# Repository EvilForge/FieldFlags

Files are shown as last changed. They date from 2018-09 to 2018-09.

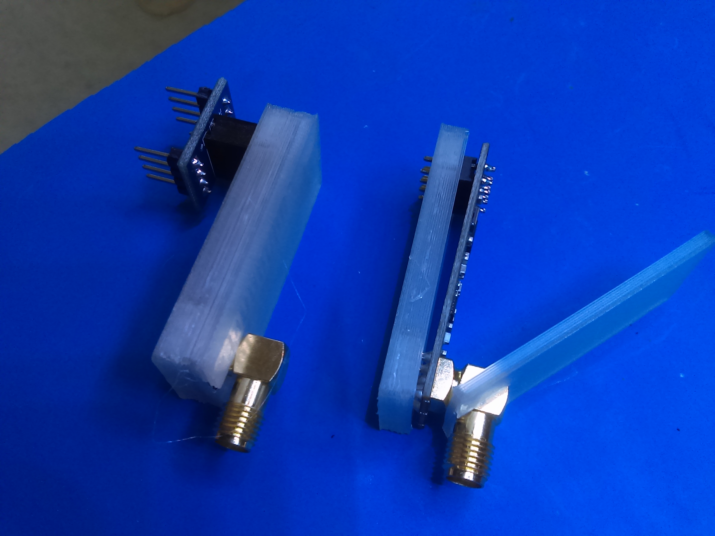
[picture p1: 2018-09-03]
IMAG0442.jpg

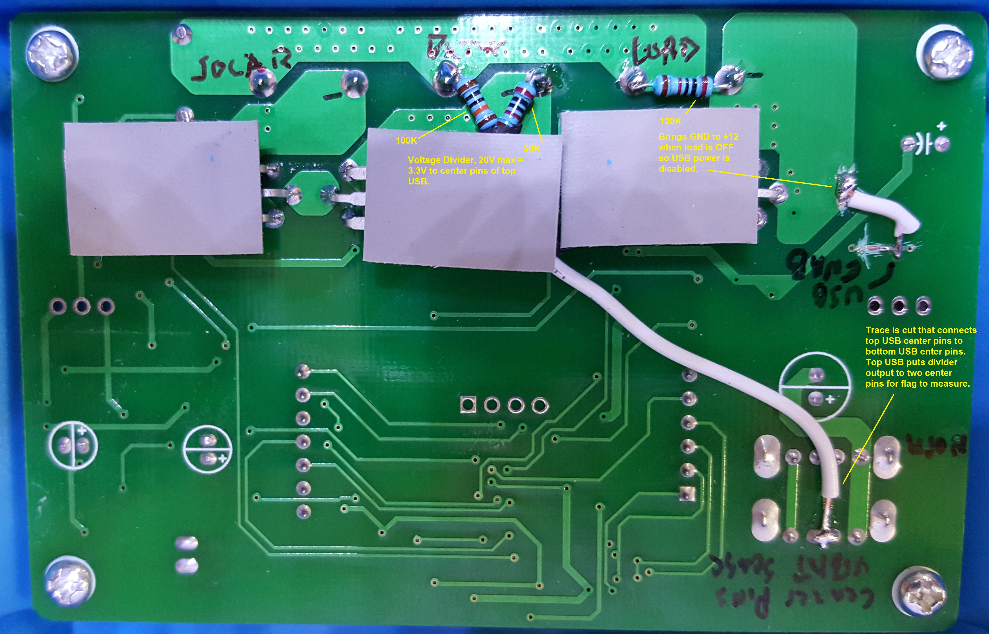
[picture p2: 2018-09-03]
SolarCharge-Bent.jpg

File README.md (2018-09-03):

# FieldFlags
An airsoft field remote flag (wireless mesh) system with internet feedback and control for players and operators.

This was a project I have abandoned, but got fairly well into things before I ran out of time and energy to tweak it. Unfortunately, there are multiple constraints such as very slow internet connectivity and multiple wireless interference issues as well as the code starting to get very complex. 

Ideally, this is a esp8266 main controller, with pro mini nodes and repeaters that all use the NRF24L01 radios to form a healing mesh network on the 2.4 GHz band (not wifi, but the same frequency).  The main controller is centrally located on the field and uses a wireless hotspot to report data and take commands from a web server running php, and mysql for a db. 

A web page that the field operators access allows statistics for the game play, field light control, and another web page can offer the players read only status updates.

Different game modes are baked into the controller but the most useful one - aside from general get read, game on, game end feedback to the players, was capture the flag mode, as the system would track the amount of time the player teams owned each flag.

This system was used in a few large events and did work in the basic mode but started to fail constantly, due to unknown reasons. I suspect wireless band interference (perhaps due to lots of drones in use?), but as the nodes are all pro mini theres not a lot of ways i could easily (or cost effectively) really do debug logging.

We also tried to add in a node that could play prerecorded mp3 sounds or songs based on a trigger from the admin, however, the current demands of the drok mp3 player made that flag consume a lot of battery.. and there was a limit to how much we could spend on solar charging and battery systems.

So I've released the code and work i did up to this point to the community, in hopes that it might help someone else out. Note than in a large part the framework for nodes and reporting and traffic management was handled by the mysensors 2.1 framework. I generally modded and enhanced the code for my uses and did not use a typical setup with a windows or ras-pi or other "controller" as you would in a home automation scenario.. in this system the wifi gateway also did a lot of the code and game flow work, in conjunction with getting and sending data to the mysqldb via php.

Note that i really dont think this is a bad setup - you may have a much simpler scenario where you just need to remotely alert people across a large area about status.. this setup might work realy well for that - but then the basic mysensors network might also do that without having to add in the mods that i used, either.

Enjoy! I wont be supporting this but if i notice a question i'll try to answer as much as i can remember..

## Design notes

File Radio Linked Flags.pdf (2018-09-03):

NOTICE – This manual is part of a system designed for use by the D14 airsoft fields for entertainment and game control purposes. No item described in this document is dangerous or life-threatening in the course of normal Airsoft Game Rules. All trademarked names and logos and titles are owned by their respective copyright owners and all use is claimed as “fair use” for parody purposes.

# OPERATING MANUAL: RADIO LINKED FLAGS

SYSTEM OVERVIEW

The radio linked flag system is based on concepts and a large amount of work completed by the MySensors.org group. While the main intent of the MySensors system is home automation, the system appears suitable for use to control game play and various devices on the D14 Airsoft field. Extensive customization is included in the resulting system. While the system is NOT intended to be resold, submission of the customized code used in the project will generally NOT be released back to the open source community at this time.

The MySensors.org system implemented at D14 relies on cheap microcontrollers (Arduino NANOs) connected to a low cost RF radio (nRF24L01) which act as “nodes”in a multi-tier star organization. End nodes transmit to repeater nodes, which in turn talk to either the gateway node or other repeater nodes. The gateway connects to a controller, which controls the commands issued to the node. End nodes can move around physically (repeating nodes should not move however) and will reattach to the network. Addressing and routing of the nodes is controlled by the nodes, repeaters and gateway nodes.

Authorization and digital signing of messages is implemented to prevent rogue interference or MITM attacks (either by players or who knows what!). Each node has a hard coded ID number, representing a flag or building or device.

The following manual is intended for qualified personnel only. Operation and deployment of the radio linked flags requires familiarity with the operating modes and options for maximum effectiveness. Your effort in reviewing and practicing with the system, as well as anticipating how adept the players are at following the instructions, will be rewarded with smooth gameplay and maximum player involvement.

What follows is the installation, operation and maintenance guide for this system.

LOCATION OF INSTALLATIONS

The radio-linked flag installation is spread across the D14 playing field. Due to the size of the field (45+ acres) having admin staff keep up to date on flag status (who owns it) or control players (start/stop games) is a significant burden. Flags may have up to 500 meters between them, but are mainly clustered around the town center. Ideally placed, the “comms” building is intended to look like a communications outpost, and in in fact, the ideal location for the gateway and possibly the controller node as well.

CONTENTS

NORMAL OPERATION PROCEDURES

FLAG NODE MODES OF OPERATION

The flag node contains one button, an RGB light and a beeper as the primary means of interacting with players. Generally, players press a button on the flag to advance thru the colors of the flag, or to indicate they are ready to begin gameplay.

The flag has several different “modes” and the light and buzzer vary with each mode:

Flag Mode | Light | Sound
Sleeping | Off | None
Game ON | Solid Green | 3- 1 sec beeps, 1 2 sec beep (like a light tree race start)
Standby | Solid Yellow | 1 sec beep when mode starts
Two Minute Warning | White/Green alternates twice with 2 sec pause, repeats 3 times. | Beep when white shown, in sync with white light.
Game END | Solid Red | 15 second solid tone.
Blind Man/Distress | Red SOS flash | SOS Beep
GREEN CONTROLLED | Green solid, with 1/4s no color every second. | 1 beep per second.
TAN CONTROLLED | Orange solid, with 1/4s no color every second | 2 beeps together, every second.
BLUE CONTROLLED | Blue Solid, with 1/4s no color every second | 3 beeps together, every second.

More stuff here…

STRONG RF EMISSIONS NEAR THE NODES MAY INTERRUPT COMMUNICATIONS. IT IS RECCOMMENDED THAT HIGH POWER RADIOS DOE ONT TRANSMIT NEAR NODES AND OTHER 2.4-2.5GHZ DEVICES (BLUETOOTH, DRONES, WIFI) ARE NOT OPERATED WITHIN SEVERAL FEET OF THE DEVICE.

WARNING. ALWAYS HAVE A BACKUP GAME PLAY PLAN IN CASE THE SYSTEM IS DOWN. SEVERAL DIFFERENT KINDS OF ISSUES CAN AFFECT THE RADIO LINKS, FROM WEATHER TO INTERFERENCE TO TERRAIN AND VEGETATION GROWTH, TO COLORBLIND PLAYERS. BE PREPARED!

INITIAL CONFIGURATION/RECONFIGURATION

Initial configuration or altering the system settings is performed by accessing the programming menu.

PROGRAMMING MENU DETAILS

PROP INTEGRATION NOTE

Props used on the field can be integrated into the system. The expected minimum amount of integration will allow starting or resetting the prop remotely, finding its status, and in some cases remotely disabling or detonating the device. However, in the initial deployment, props will not be incorporated.

FLAG GAME – FLAG CONTROL

Junk junk junk

GAME FLOW

The initial flow of this game is as follows:

1. System blah blah

SYSTEM MAINTENANCE

OVERVIEW

System maintenance includes items such as pre-operation checks, battery charging and replacement, and node replacement. The system is generally built to handle normal use but any time the device is dropped, kicked or knocked over, an inspection of the device should be performed.

Modifying the code operation – aside from the configuration options in the programming menu – is not covered in this manual. The unit uses C++ Arduino style programming language with an Arduino Nano controller and an nRF24L01+ radio device, and does support direct USB connections for reprogramming. Please contact the D14 owners for questions about the program source code or design documentation.

TROUBLESHOOTING NODE CONNECTIVITY

Note that if a node cannot connect at power-up there may be.

Strong RF emissions near the device have been proven to cause undesired operation, including hanging the controller, erroneous entry, etc. It is recommended that RF transmitters are NOT operated within several feet of the device.

If the device display becomes garbled or appears to hang, power the system down with the access key, then power it back on. The last program will be restarted.

If the buzzer or LEDs run continuously, the MOSFET devices may have failed. MOSFET devices typically (eventually) fail as a short circuit. Turn off the node and replace it with a functioning node if a power cycle does not resolve the issue.

OPENING THE NODE CASE

The case should be opened using the….

ALWAYS DISCONNECT ONE OR BOTH OF THE MAIN BATTERY CONNECTORS WHEN PERFORMING SERVICE.

MOSFETS AND SEVERAL COMPONENTS ARE ‘GROUND-SWITCHED’. WHICH MEANS THEY RECEIVE CONSTANT POWER FROM THE BATTERY + RAIL, AND GROUND IS SWITCHED BY THE MOSFET DEVICES. THIS MEANS THE MOSFET TABS AND HEAT-SINKS WILL NORMALLY BE RESTING AT +12VDC DURING OPERATION.

BATTERY CHARGING

The on-board solar charging circuit may take several hours due to battery capacity. Battery is considered charged when the voltage reaches 11 VDC. Battery voltage less than 9V is not recommended and can damage the NiMh battery.

If a battery is dead and the node is needed for gameplay immediately, swap the NiMh battery with a charged one.

NOTE – THE INTERNAL CHARGER IS INTELLIGENT, AND WILL SWITCH TO FLOAT MODE AUTOMATICALLY. THE DEVICE CAN BE LEFT PLUGGED IN INDEFINITELY WITHOUT CAUSING BATTERY DAMAGE.

BATTERY REPLACEMENT

As this unit uses a 9.6V NiMh Airsoft battery with a deans connector. Please replace the battery with a suitable sized replacement.

Unscrew the bracket holding the battery down and one or more of the side screws to free the battery.

This is a standard battery design, and any battery with similar specifications can be used – whether it was sold for airsoft or R/C use. A higher capacity battery will provide more run time during low sunlight periods, but the current draw of the flag is not high and does not require high capacity batteries.

Dispose of or recycle according to local ordinances.

FUSE REPLACEMENT

Fuses should not typically blow unless an internal short develops in the device or a component. Before replacing a fuse, investigate the component that blew the fuse and verify it is not malfunctioning. If the main 3A fuse blows, open the battery cover to switch it out.

Component | Fuse Size | Purpose
Main Battery 3 | 3A | Main power for all systems.

AUXILLARY INFORMATION/SPECIFICATIONS

FLAG NODE INTERNAL COMPONENT LIST

The following components are used in this device.

Component

Main Battery. 9.6V NiMh battery with deans connector. 3A Main fuse on battery.

Control box. Arduino Nano controller with custom program, power regulation as well as control MOSFET switches and the radio module. Control system fuses and battery charger. Main power switch turns on the control electronics and LED/audio.

“Main Button” – main button used to interact with the device.

Power Switch. Switches power to control box only – however this will generally turn off all components. The charger will operate regardless of system power switch state.

LED display – Red, Blue and Green LED displays.

INTERNAL COMPONENTS:

CONTROL BOX:

MAIN CPU BOARD

MISCELLANEOUS SPECS:

Weight: .3 Kg or 2 lbs.

Width: 0.1M or 4 in.

Height: 0.3M or 10 in.

Power Supply: Internal 9.6V NiMh battery, deans connector.

Power Draw: 3A Max, intermittent. 2mA in sleep mode.

Theoretical Battery Life – 8Ahr/(1A average)=8 hours? Exact time estimates depend heavily on options chosen and amount of game play, as well as amount of available strong sunlight.
Date of Creation: September 31st, 2016.

Paint Codes: RUST-OLEUM Hammered spray paints, Silver 7213

Fuel Rod/Canister modification: The fuel rods or canisters must have a strong magnet to trigger the sensor in the bottom left canister slot (over the left support). A small strong magnet is embedded in the bottom of the canister slot to trigger Fuel Rod sensors as well.

Schematic:

QUICK REFERENCE SHEET

Print copies of the following sheet for in-field reference.

DISCLAIMER AND WARNINGS

This device is designed to enhance game play in an Airsoft scenario game. It is not dangerous or life threatening, assuming normal Airsoft game play rules are followed. Following typical rules, especially eye protection, when the BB Cannon is enabled should protect players from injury. The device is not intended to be moved during game play, especially by less than 2 people. Always instruct players to keep clear of the BB Cannon at all times, regardless of whether the system is powered or armed. When not in use, cover the cannon to prevent debris from entering or protect if accidental discharge occurs.

While it should be readily apparent to anyone this is a prop, based on design, it is still prudent to cover and conceal the device from general public view when not in use on the playing field.

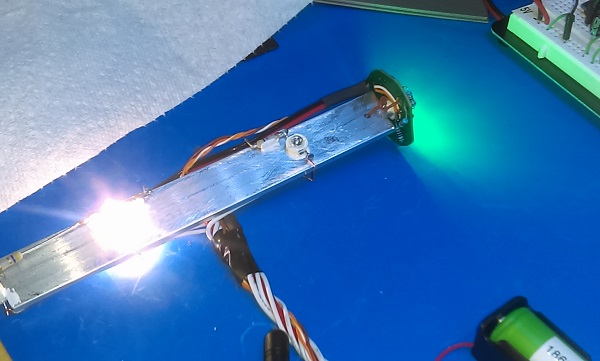
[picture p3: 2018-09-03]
IMAG0454.jpg

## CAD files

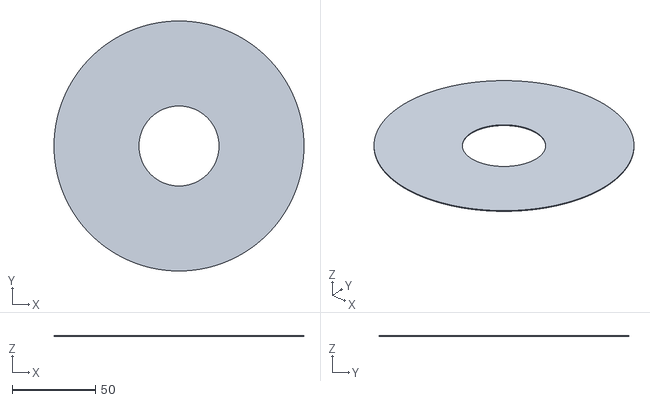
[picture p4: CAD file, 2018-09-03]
Flag LED SunShield.stl
150.0 x 150.0 x 0.5

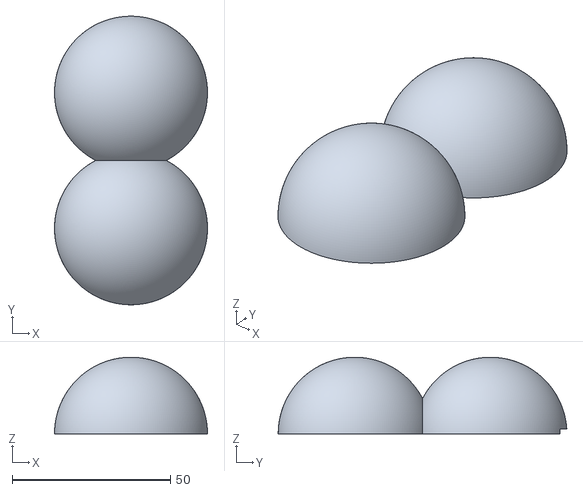
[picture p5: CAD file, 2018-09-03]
Flag LED Bubble.stl
48.4 x 91.3 x 24.2

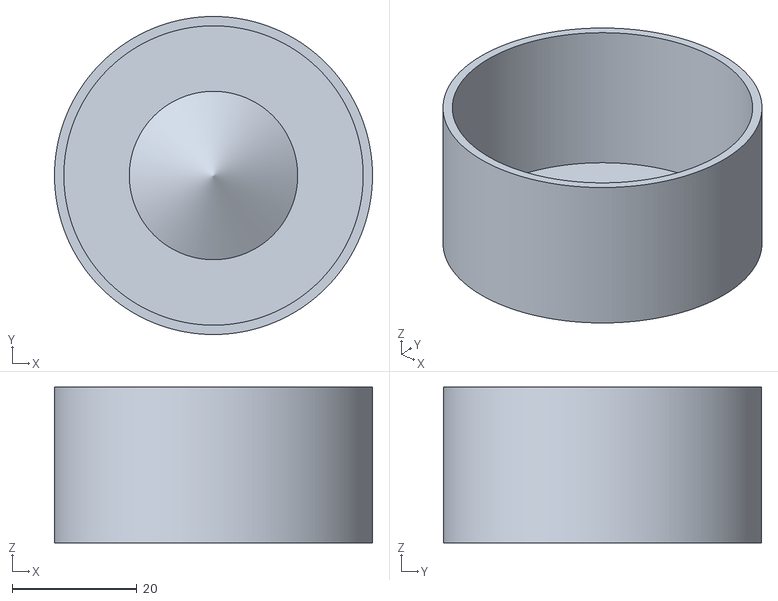
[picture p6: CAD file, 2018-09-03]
Flag LED Top.stl
51.0 x 51.0 x 25.0

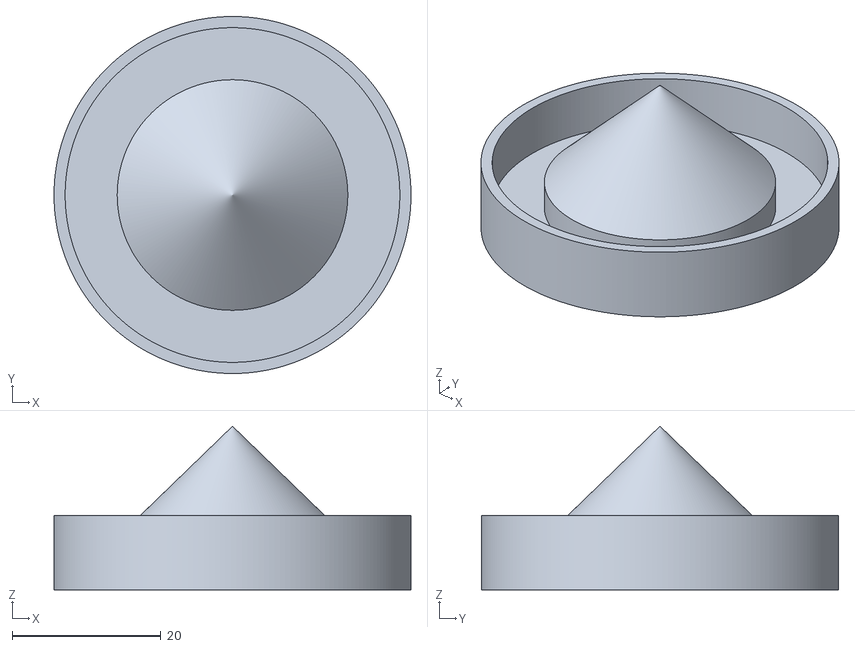
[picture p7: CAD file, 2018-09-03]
Flag LED Tube Top.stl
48.0 x 48.0 x 22.0

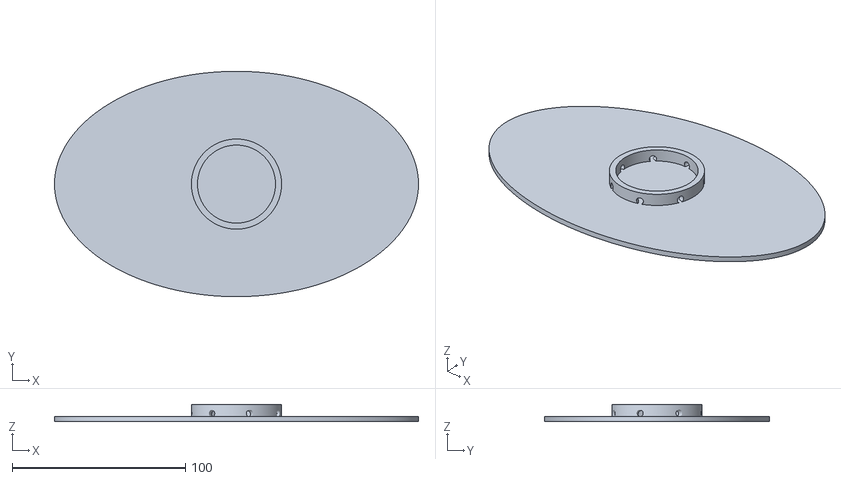
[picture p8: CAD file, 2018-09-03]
Flag LED Wide Top.stl
210.0 x 130.0 x 10.0

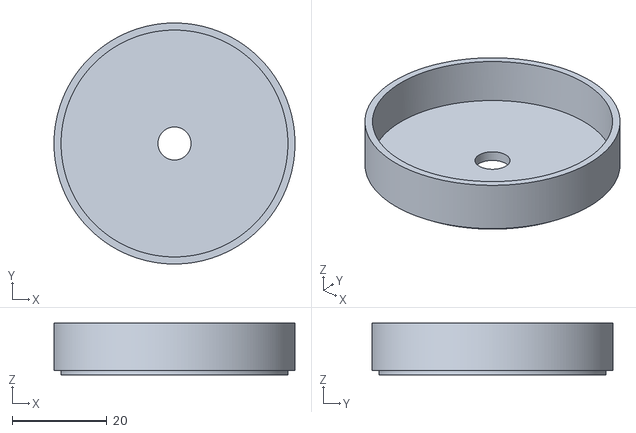
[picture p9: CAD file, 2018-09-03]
Flag LED Spacer.stl
51.0 x 51.0 x 11.0

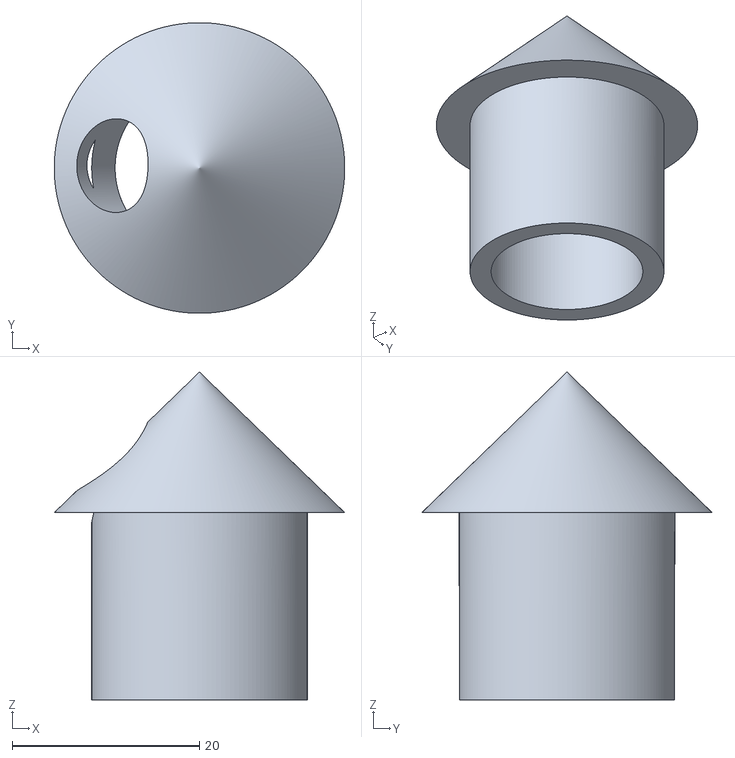
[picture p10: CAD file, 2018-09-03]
Flag LED Tube Base.stl
31.0 x 31.0 x 35.0

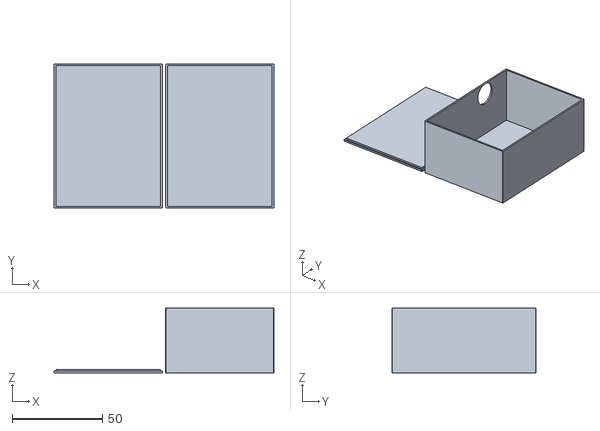
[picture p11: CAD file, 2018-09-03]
Flag GW Box.stl
121.9 x 80.0 x 36.0

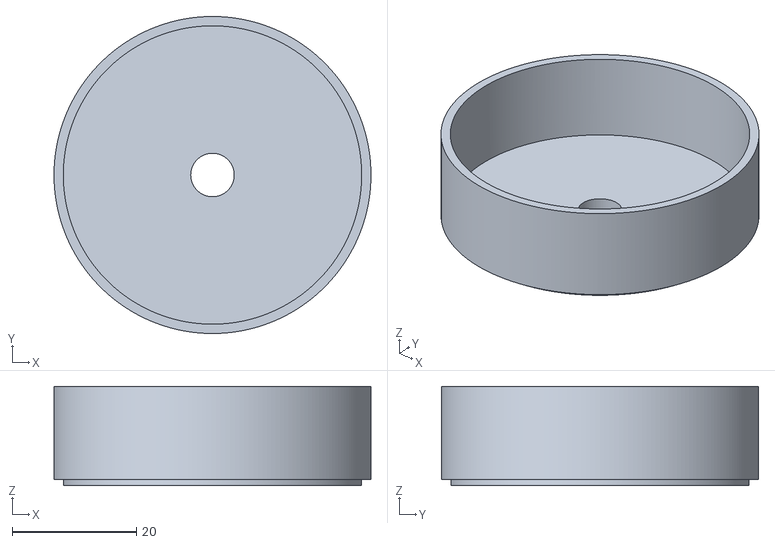
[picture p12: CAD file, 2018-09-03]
Flag LED Mid.stl
51.0 x 51.0 x 16.0

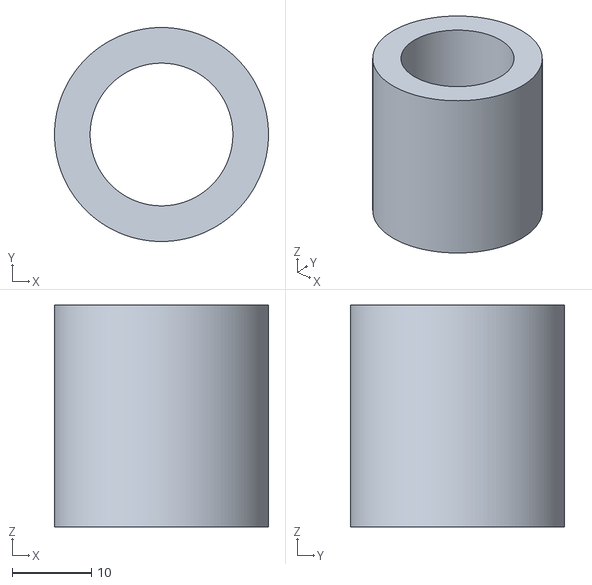
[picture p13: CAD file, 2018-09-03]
Flag Pole Bushing.stl
27.0 x 27.0 x 28.0

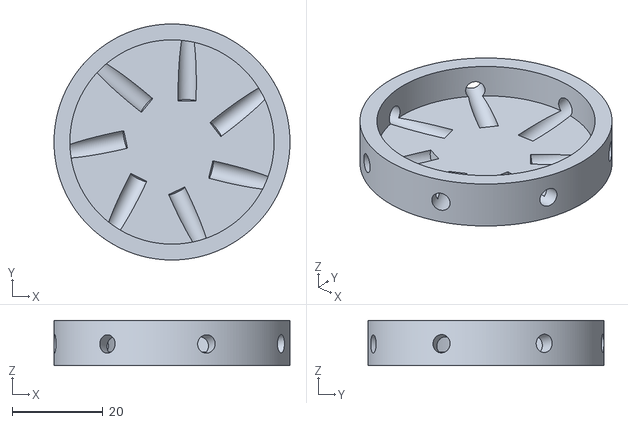
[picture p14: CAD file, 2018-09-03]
Flag LED New Top.stl
52.0 x 52.0 x 10.00

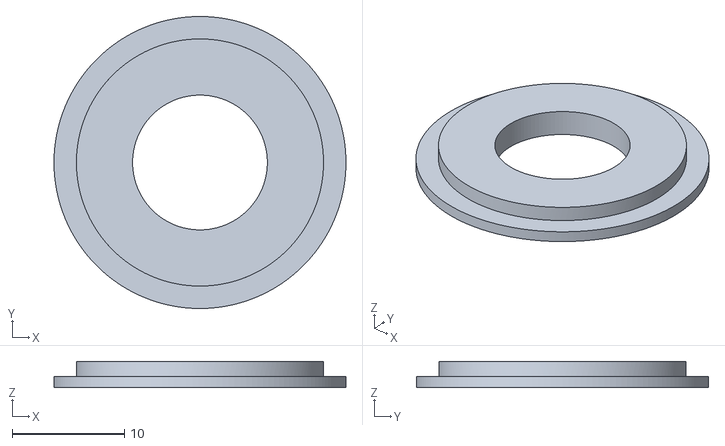
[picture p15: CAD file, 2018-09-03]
Flag Switch Bushing.stl
26.0 x 26.0 x 2.35

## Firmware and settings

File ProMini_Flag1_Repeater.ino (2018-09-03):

// ProMini E-Flag Repeater. Copyright Reid Bush 2017
//#define MY_DEBUG // Keep Debug off, it uses tons of prog memory.
#define MY_REPEATER_FEATURE
#define MY_RADIO_NRF24
#define MY_RF24_PA_LEVEL RF24_PA_MAX
#define MY_RF24_CHANNEL 83
#define MY_NODE_ID 1
#define SN "Flag_Node"
#define SV "2.0"
#define MY_BAUD_RATE 9600

#define Start_Byte 0x7E // MP3 CMD Start Byte
#define Version_Byte 0xFF // MP3 CMD Version Byte
#define Command_Length 0x06 // MP3 CMD Length Byte
#define End_Byte 0xEF // MP3 CMD End Byte
#define Acknowledge 0x00 //Returns info with command 0x41 [0x01: info, 0x00: no info]

#define BTN_PIN 2 // Button Sense Pin
#define MP3_PIN 7 // PIN for MP3 power control.
#define VOLT_PIN 0 // Analog pin for volt reading.
#define LED_PIN 5 //  PIN for serial to ws2812s.
#define PS_PIN 6 // PIN for LED power control (inverted).
#include <WS2812.h>
#include <FLAGSTAT.h>
#include <SPI.h>
#include <MySensors.h>

MyMessage statusMsg(0, V_VAR1); // Invoke Mysensors Message for Status
MyMessage spawnMsg(0, V_VAR2); // Invoke Mysensors Message for Spawn Delay
int sleepLower = 25000; // Lower limit of sleep timeout.
int sleepUpper = 45000; // Upper limit of sleep timeout.
bool buttonStatus = false;  // False = Not pressed.
bool disabled = false; // Flag Disabled mode.
bool ledGreen = false; // Tracks LED flashing from green/yellow for spawn limits.
bool trapSet = false; // Tracks Spawn Trap.
bool ownerLocked = true; // Tracks whether owner changes are locked out. AKA not owner 5 from GW.
bool announced = false; // Tracks whether mode has been announced yet.
byte currentMode = 1;  // Current Flag Mode.
byte modeStage = 0; // What stage the mode is running.
byte modeLEDVal = 0; // Stores the mode LED value for owner changes.
byte owner = 0; // what color owns the flag.
byte packedByte = 0;
long rndSleep = 0; // value to hold random sleep period.
unsigned long mp3PowerCut = 0; // Millis when we want to power down the MP3 module.
unsigned long mp3Ready = 0; // Millis when we want to send MP3 commands (power on delay).
unsigned long nextTimerCheck = 0; // Millis when we want to start some other action.
unsigned long nextUpdate = 0; // When to turn off this LED and move to the next one.
unsigned long nextBattCheck = 0; // When to check the battery next time 120s.
unsigned long btnHoldOff = 0; // makes button routines wait for debounce.
unsigned long lastGWMsg = 0; // Stores the last time we saw a message from the gateway. After some time, assume we lost contact.
unsigned long spawnDelay = 30000; // Stores amount of time to wait for next spawn. Default 30s
unsigned long spawnLimit = 0; // Stores milis when next spawn is allowed.
unsigned long btnStart = 0; // Tracks when button was first pressed.
FLAGSTAT flagStat; // Initialize the class for working with flag status.
WS2812 LED(10); // Set num of LEDs to 10

void setup() {
  Serial.begin(9600); // NOTE Serial TX is used to control MP3 also!
  randomSeed(analogRead(7));
  pinMode(BTN_PIN, INPUT_PULLUP); // Set Button Sense pin to float high.
  pinMode(VOLT_PIN, INPUT); // Voltage Sense pin
  pinMode(PS_PIN, OUTPUT); 
  digitalWrite(PS_PIN,0); // Turn on power - Its inverted.
  pinMode(MP3_PIN, OUTPUT); 
  digitalWrite(MP3_PIN,1); // Turn on power.
  // LED setup section.
  LED.setColorOrderGRB();
  LED.setOutput(LED_PIN);
  wait(1000);
  execute_CMD(0x12, 1, 14); // Play file 30-1E
  allLEDs(1, 1);
  wait(1000);
  allLEDs(4, 4);
  mp3PowerCut = millis() + 2000; // Set mp3 power cutoff to 2 secs.
  wait(300);
  allLEDs(0, 0);
  wait(20);
  request( 0, V_VAR1 ); // Pull the gateway's current flag mode - switch to this when node powers up.
  request( 0, V_VAR2 ); // Pull the gateway's current spawn delay - switch to this when node powers up.
}

void presentation() {
  present(0, S_CUSTOM); // Present Sensor 0 as a custom type. (status)
  present(1, S_CUSTOM); // Present Sensor 1 as a custom type. (spawn)
  sendSketchInfo(SN, SV);
}

// DF serial command code
void execute_CMD(byte CMD, byte Par1, byte Par2) { // Excecute the command and parameters
  // Calculate the checksum (2 bytes)
  int16_t checksum = -(Version_Byte + Command_Length + CMD + Acknowledge + Par1 + Par2);
  // Build the command line
  byte Command_line[10] = { Start_Byte, Version_Byte, Command_Length, CMD, Acknowledge, Par1, Par2, checksum >> 8, checksum & 0xFF, End_Byte};
  //Send the command line to the module
  for (byte k=0; k<10; k++)
  {
    Serial.write( Command_line[k]);
  }
}

void loop() {
  if (nextUpdate < millis()) {
    packedByte = flagStat.setButton(buttonStatus, packedByte);
    packedByte = flagStat.setMode(currentMode, packedByte);
    packedByte = flagStat.setOwner(owner, packedByte);
    send(statusMsg.set(packedByte) );
    nextUpdate = millis() + 30000;
  }
  if (millis() > mp3PowerCut) {
    digitalWrite(MP3_PIN,0); // Turn off power.
  }
  if (nextBattCheck < millis()) {
    double battVoltage = (analogRead(VOLT_PIN) / 32.8);
    int battPct = (((battVoltage - 11.9)) * 130);
    if (battPct > 110) battPct = 110;
    Serial.println("Bat:" + String(battVoltage) + " " + String(battPct) + "%");
    if (battVoltage < 12) { // we get false low bat sometimes. double check it after 10 ms.
      wait(10);
      battVoltage = (analogRead(VOLT_PIN) / 32.8);
      battPct = (((battVoltage - 11.9)) * 130);
      if (battPct > 110) battPct = 110;
      Serial.println("LowBatVerify:" + String(battVoltage) + " " + String(battPct) + "%");
    }
    sendBatteryLevel(battPct);
    if (battVoltage < 12) { // If batt is critical, sleep for 5 minutes. otherwise use normal 25-45 secs.
      Serial.println(F("LowBatSleep"));
      currentMode = 0;
      sleepLower = 300000;
      sleepUpper = 300010;
      send( statusMsg.set(packedByte) ); // Inform the gateway of the current flag Mode (sleep).
    } else {
      sleepLower = 20000; // This should be 20 to 30 seconds normally.
      sleepUpper = 30000;
    }
    nextBattCheck = millis() + 120000;
  }
  if ((millis() - lastGWMsg) > 1800000) {
    // No contact for 30 minutes. Reset to sleep mode.
    currentMode = 0;
    owner = 0;
    allLEDs(0, 0);
    wait(100);
    digitalWrite(PS_PIN,1); // Turn off power - Its inverted.
    digitalWrite(MP3_PIN,0); // Turn off power.
    Serial.println(F("GW Timeout, sleeping."));
  }
  if ((millis() - lastGWMsg) > 3600000) {
    // No contact for 1 hour. Reset to disabled mode.
    disabled = true;
    Serial.println(F("GW Timeout, disabled."));
  }
  if (disabled) {
    Serial.println(F("Disabled."));
    wait(100);
    digitalWrite(PS_PIN,1); // Turn off power - Its inverted.
    digitalWrite(MP3_PIN,0); // Turn off power.
    wait(15000); // Wait 15 secs to bleed any child messages off.
    sleep(BTN_PIN, FALLING, 120000); // But - a repeater flag wont truly sleep.. :(
    request( 0, V_VAR1 ); // Pull the gateway's current flag mode - switch to this when node powers up.
    request( 0, V_VAR2 ); // Pull the gateway's current spawn delay - switch to this when node powers up.
  }
  switch (currentMode) {
    case 0: // Sleep Mode. Wait for around a second. No LED but we still process radio msgs.
      nextUpdate += 270000;
      allLEDs(0, 0);
      wait(100);
      digitalWrite(PS_PIN,1); // Turn off power - Its inverted.
      digitalWrite(MP3_PIN,0); // Turn off power.
      rndSleep = random(sleepLower, sleepUpper);
      Serial.println("Sleep " + String(rndSleep));
      wait(rndSleep);
      request( 0, V_VAR1 ); // Pull the gateway's current flag mode - switch to this when node powers up.
      request( 0, V_VAR2 ); // Pull the gateway's current spawn delay - switch to this when node powers up.
      break;
    case 1: // Standby (pre game)
      if ((modeStage == 0) && (nextTimerCheck < millis()))  {
        Serial.println(F("StandBy"));
        allLEDs(5, owner);
        nextTimerCheck = millis() + 1000;
        modeStage ++;
      }
      if ((modeStage == 1) && (nextTimerCheck < millis()) ) {
        nextTimerCheck  = millis() + 1000;
        modeStage = 0;
        allLEDs(3, owner);
      }
      break;
    case 2: // Game On
      if ((!announced) && (mp3Ready < millis())) {
        execute_CMD(0x12, 0, 2); // Play file 2-02
        announced = true;
      }
      if ((nextTimerCheck < millis()) ) { // Game on is always green but we dont try forcing the color every pass. 
        Serial.println(F("GameOn"));
        allLEDs(4, owner);
        nextTimerCheck = millis() + 10000;
      }
      break;
    case 3: // Spawn Point
    case 4: // Spawn Trap
      if ((!announced) && (mp3Ready < millis())) {
        execute_CMD(0x12, 0, 2); // Play file 2-02
        announced = true;
      }
      if ((modeStage == 0) && (nextTimerCheck < millis())) { // show green wait for press.
//        Serial.println(String(millis()) + " ms:0");
        allLEDs(4, owner);
        nextTimerCheck = millis() + 150;
        if (digitalRead(BTN_PIN) == LOW) {
          if (trapSet && (currentMode = 4)) {
            modeStage = 3;
            nextTimerCheck = 0;
            spawnLimit = millis() + (spawnDelay * 3);
          } else {
            modeStage ++;
            btnStart = millis();
          }
        }
      }
      if ((modeStage == 1) && (nextTimerCheck < millis())) { // wait for release.
//        Serial.println(String(millis()) + " ms:1 BtnWait");
        nextTimerCheck = millis() + 150;
        if ((digitalRead(BTN_PIN) == HIGH) && ((millis() - btnStart) < 20000)) {
            // btn released before trap set. Goto stage 2
            modeStage ++;
            nextTimerCheck = 0;
            spawnLimit = millis() + spawnDelay;
//            Serial.println("SpawnLImit:" + String(spawnLimit));
        }
        if ( ((millis() - btnStart) > 20000) && (currentMode==4) ) {
            // btn held past trap set point.
            trapSet = true;
            modeStage = 4;
            nextTimerCheck = 0;
            spawnLimit = millis() + 5000;
          }
      }
      if ((modeStage == 2) && (nextTimerCheck < millis())) { // if < 20s flash yellow till end of timeout.
//        Serial.println(String(millis()) + " ms:2 Spawn waiting");
        nextTimerCheck = millis() + 150;
        if (ledGreen) {
          allLEDs(0,owner);
          ledGreen = false;
        } else {
          allLEDs(5,owner);
          ledGreen = true;
        }
        if (spawnLimit < millis()) {
          // delay met, allow spawn.
          Serial.println(F("Spawn Allowed."));
          allLEDs(4,owner);
          modeStage = 0;
          nextTimerCheck = millis() + 3000;
        }
      }
      if ((modeStage == 3) && (nextTimerCheck < millis())) { // trap set off
//        Serial.println(String(millis()) + " ms:3 Triggered");
        allLEDs(2,6);
        nextTimerCheck = millis() + 50;
        if (spawnLimit < millis()) {
          modeStage = 0;
          trapSet = false;
          nextTimerCheck = 0;
        }
      }
      if ((modeStage == 4) && (nextTimerCheck < millis())) { // trap Set Acknowledged
//        Serial.println(String(millis()) + " ms:4 Trap Ack");
        nextTimerCheck = millis() + 150;
        if (ledGreen) {
          allLEDs(4,owner);
          ledGreen = false;
        } else {
          allLEDs(5,owner);
          ledGreen = true;
        }
        if (spawnLimit < millis()) {
          modeStage = 0;
          nextTimerCheck = 0;
        }
      }
      break;
    case 5: //Two Minute Warning
      if ((!announced) && (mp3Ready < millis())) {
        execute_CMD(0x12, 0, 3); // Play file 3-03
        announced = true;
      }
      if (modeStage == 0) { // Mode 0 - Start of mode.
        Serial.println(F("2-Min"));
        allLEDs(1, owner);
        modeStage ++; // White 200ms flash.
        nextTimerCheck = millis() + 200;
      }
      if ( (modeStage == 1) && (nextTimerCheck < millis()) ) {
        allLEDs(0, owner);
        modeStage ++; // Off 100ms.
        nextTimerCheck = millis() + 100;
      }
      if ((modeStage == 2) && (nextTimerCheck < millis()) ) {
        allLEDs(1, owner);
        modeStage ++; // White 200ms flash.
        nextTimerCheck = millis() + 200;
      }
      if ( (modeStage == 3) && (nextTimerCheck < millis()) ) {
        allLEDs(0, owner); // Off 100ms.
        nextTimerCheck = millis() + 100;
        modeStage ++;
      }
      if ((modeStage == 4) && (nextTimerCheck < millis()) ) {
        allLEDs(4, owner); // Green 10s.
        nextTimerCheck = millis() + 7000;
        modeStage ++;
      }
      if ((modeStage == 5) && (nextTimerCheck < millis()) ) {
        allLEDs(4, owner); // Restart Flash Sequence.
        nextTimerCheck = millis();
        modeStage = 0;
      }
      break;
    case 6: // Game End
      if ((!announced) && (mp3Ready < millis())) {
        execute_CMD(0x12, 0, 4); // Play file 4-04
        announced = true;
      }
      if (modeStage == 0) { // Mode 0 - Start of mode.
        Serial.println(F("Game End"));
        allLEDs(2, 0);
        nextTimerCheck = millis() + 180000;
        modeStage = 1; // Mode 1 - waiting 3m.
      }
      if ((modeStage == 1) && (nextTimerCheck < millis())) { // Game End > 3m, turn off lights.
        nextTimerCheck  = 0;
        allLEDs(0, 0);
      }
      break;
    case 7: // Blind Man
      if ((!announced) && (mp3Ready < millis())) {
        execute_CMD(0x12, 0, 5); // Play file 5-05
        mp3Ready = millis() + 10000;
        mp3PowerCut = millis() + 20000;
        announced = false;
      }
      if ((modeStage == 0) && (nextTimerCheck < millis())) { // Mode 0 - Start of mode.
        Serial.println(F("Blind Man!"));
        allLEDs(2, 2);
        nextTimerCheck  = millis() + 200;
        modeStage ++; // Mode 1 - waiting .5 seconds.
      }
      if ((modeStage == 1) && (nextTimerCheck < millis())) {
        nextTimerCheck  = millis() + 200;
        modeStage = 0;
        allLEDs(5, 7);
      }
      break;
  }
  if (btnHoldOff < millis()) {
    if ((digitalRead(BTN_PIN) == LOW) && (!buttonStatus)) {
      buttonStatus = true;
      packedByte = flagStat.setButton(buttonStatus, packedByte);
      send(statusMsg.set(packedByte) );
      Serial.println(F("BDown"));
      btnHoldOff = millis() + 150;
      digitalWrite(MP3_PIN,1); // Turn on power in anticipation of announcing mode.
      mp3PowerCut = millis() + 10000; // set power off in 10 secs for MP3 mpodule.
      mp3Ready = millis() + 1000;
    }
    if ((digitalRead(BTN_PIN) == HIGH) && (buttonStatus)) {
      buttonStatus = false;
      packedByte = flagStat.setButton(buttonStatus, packedByte);
      Serial.println(F("BUp"));
      btnHoldOff = millis() + 150; // need to verify its not spawn trap/limit, if so dont increment.
      if ( (currentMode > 1 ) && (currentMode < 6) && (!ownerLocked) ) {
        owner++;
        if (owner > 3) owner = 0;
        execute_CMD(0x12, 0, owner+6); // Play file 6+owner
        Serial.println("Play "+String(owner+6));
      }
      allLEDs(modeLEDVal, owner);
      packedByte = flagStat.setOwner(owner, packedByte);
      send(statusMsg.set(packedByte));
    }
  }
}

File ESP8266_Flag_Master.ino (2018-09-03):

#include <ESP8266HTTPClient.h>
#include <ESP8266mDNS.h>
#include <ESP8266WiFi.h>
#include <EEPROM.h>
#include <SPI.h>
#include <FLAGSTAT.h>
#include <Base64x.h>

/**
 * The gateway takes and sends data to flag nodes based on game mode and POST responses from the web server.
 * The gateway connects to a hotspot for internet and uses nRF24L01 radios for flags.
 * Packed Flag data: byte 1 = bit0-enable/disable, bit123 owner, bit456 mode, bit7 button
 * Packed Flag data: byte 2 = Battery Level
 * Packed Flag data: byte 3 = Last Seen (secs)
 */

#define MY_DEBUG 
#define MY_BAUD_RATE 9600
#define MY_RADIO_NRF24
#define MY_RF24_PA_LEVEL RF24_PA_MAX
#define MY_GATEWAY_ESP8266

//#define MY_ESP8266_SSID "D14FieldOps"
//#define MY_ESP8266_PASSWORD "D14Gateway"
//#define MY_ESP8266_SSID "xxxxx"
//#define MY_ESP8266_PASSWORD "xxxxx"
//#define MY_IP_GATEWAY_ADDRESS 192,168,1,93
#define MY_ESP8266_SSID "xxxx"
#define MY_ESP8266_PASSWORD "xxxx"
#define MY_IP_GATEWAY_ADDRESS 10,10,30,60
#define MY_IP_SUBNET_ADDRESS 255,255,255,0
#define MY_ESP8266_HOSTNAME "D14GW"
#define MY_PORT 5003      
#define MY_GATEWAY_MAX_CLIENTS 2
// Controller ip address. Enables client mode (default is "server" mode). 
// Also enable this if MY_USE_UDP is used and you want sensor data sent somewhere. 
//#define MY_CONTROLLER_IP_ADDRESS 192, 168, 178, 68
#include <MySensors.h> // Always include this last, after all #defines.

unsigned long battReport;
unsigned long heartbeat; // 3 minutes, to check all flags for heartbeat.
unsigned long fieldUpdate;
unsigned long updPeriod = 10000; // Sets how often the GW updates the web server.
const char* wwwUserName = "admin";
const char* wwwPassword = "xxxx"; // TODO - store and retrieve this from EEPROM
const char* wwwServ = "http://www.d14airsoft.com/field/process/proc.php?"; //PRODUCTION
byte flagArray[20]; // Enabled,Mode,Owner,Button - this is what the flag sent us
byte battArray[20]; // battery 0-100
byte spwnArray[20]; // Spawn Delay time 0-255
byte servArray[20]; // Enabled,Mode,Owner,Button - but this is what the server sent us
bool throttled = false; // If true, gw sleeps as the entire field is disabled.
unsigned int flagTimes[20][4]; // Units: Seconds purpose: Timestamp of last contact, green held increment, tan held..., blue held
// The idea is current millis -timestamp gives time held, add it to the existing value controlled by the owner
MyMessage statusMsg(0, V_VAR1);
MyMessage spawnMsg(1, V_VAR2);
FLAGSTAT flagStat; // Initialize the class for working with flag status.

void postTimes(byte flag) {
  HTTPClient http;
  String postLine;
  postLine="a=ft&id=" + String(flag+1) + "&tg=" + String(flagTimes[flag][1]) + "&tt=" + String(flagTimes[flag][2]) + "&tb=" + String(flagTimes[flag][3]);
//  Serial.println(String(millis()) + " PostLine: " + postLine);
  http.begin(wwwServ);
  http.addHeader("Content-Type", "application/x-www-form-urlencoded");
  int httpCode = http.POST(postLine);
  String payload = http.getString();
  http.end();
//  Serial.println("HTTP response length:" + String(payload.length()));
//  Serial.println("HTTP response:" + payload);
}

void postFlagNode() {
  // This is for posting to web servers.
  HTTPClient http;
  String postLine;
  postLine="a=u&fa=";
  int inputLen = sizeof(flagArray);
  int encodedLen = base64_enc_len(inputLen);
  char encoded[encodedLen];
  base64_encode(encoded, (char *)flagArray, inputLen); 
  postLine+=encoded;
//  Serial.println(String(millis()) + " Flag PostLine: " + postLine);
  http.begin(wwwServ);
  http.addHeader("Content-Type", "application/x-www-form-urlencoded");
  int httpCode = http.POST(postLine);
  String payload = http.getString();
  http.end();
  if ((httpCode==200) && (payload.length()>=39) && (payload.length()<=79)) {
//    Serial.println("HTTP response length:" + String(payload.length()));
//    Serial.println("HTTP response:" + payload);
    bool fieldEnabled = false;
    const char c[2]=",";
    char *value;
    int i=0;
    byte sentArray[20];
    value = strtok(&payload[0],c); // Split the incoming string by the comma token and set a byte array to the individual values.
    while( value != NULL ) {
      if (i<20) { // If its more than 20, we will overflow our array, so just stop assigning.
        sentArray[i]=atoi(value);
      }
      value = strtok(NULL, c);
      i++;
    }
    if (i=20) { // If i got something other than 20 values, something is wrong, and dont assign the incoming data.
      for (i=0;i<20;i++) {
        servArray[i]=sentArray[i];
        // Check all flags for enabled. If none are enabled at end of loop, alter web checkin to 5 minutes.
        if (flagStat.enabled(servArray[i])) {
          fieldEnabled = true;
        }
        if ((servArray[i]!=flagArray[i])) { // Something is different.
          bool doSend = false;
          if (flagStat.getMode(servArray[i])!=flagStat.getMode(flagArray[i]))  {
            doSend = true; // if the mode changed, update.
            // If its Game Over, send the times up.
            if (flagStat.getMode(servArray[i]) == 6) {
              postTimes(i);
            }
            // If the mode is now sleep, clear the flag times for the flag. 
            if (flagStat.getMode(servArray[i]) == 0) {
              flagTimes[i][1] = 0; //green
              flagTimes[i][2] = 0; //tan
              flagTimes[i][3] = 0; //blue
            }
          }
          if (flagStat.enabled(servArray[i])!=flagStat.enabled(flagArray[i])) {
            doSend = true; // if the enabled changed, update.
            // Clear the flag times for the flag in question, if the mode is now off.
            if (flagStat.enabled(servArray[i])==false) {
              flagTimes[i][1] = 0; //green
              flagTimes[i][2] = 0; //tan
              flagTimes[i][3] = 0; //blue
            }
          }
          if ( (flagStat.getOwner(servArray[i])!=flagStat.getOwner(flagArray[i])) && (flagStat.getOwner(servArray[i])!=5) ) {
            doSend = true; // if the owner is different, and desired <> 5 dont care, update.
          }
          if (doSend && (transportGetRoute(i+1) != 255)) { // If we need to send data to a flag, and we know the route to it...
            statusMsg.setDestination(i+1);
            send(statusMsg.set(servArray[i]));
          }
        }
      }
    }
    if (fieldEnabled) {
      updPeriod = 10000;
      throttled = false;
    } else {
      updPeriod = 60000; // Should be 5 minutes if field is disabled - 300000.
      throttled = true;
      Serial.println("All Flags DISABLED. Web update is throttled!");
    }
  } else {
    Serial.println("Flag HTTP code:" + String(httpCode));
    Serial.println("Flag HTTP response:" + payload);      
  }
}
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

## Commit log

2018-09-03 Project Images
    Some of the project images and design of indicators and node control boards.
2018-09-03 ESP8266 Flag Master Arduino Code
    The gateway code that links the field to the web server and the field and includes some of the gameplay workflow.
2018-09-03 FLAGSTAT library
    The arduino library i used to take over some of the really common code routines i used over and over..
2018-09-03 A Flag Node arduino code
    A node that repeats data to other nodes and also has the LED indicators. MP3 player capability was also in this but I only created one actual node with an MP3 capability, as a test.
2018-09-03 3d Printer files for flags
    Printer files for the various 3d printed parts i used.
    [Flag GW Box.stl, Flag LED Bubble.stl, Flag LED Mid.stl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]
